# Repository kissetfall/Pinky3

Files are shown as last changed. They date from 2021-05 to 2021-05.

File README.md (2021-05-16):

# Pinky3

Pinky3 fork with rotary encoders and kailh hotswaps for thumb row.
This is a WIP, but it's already works great for daily use.

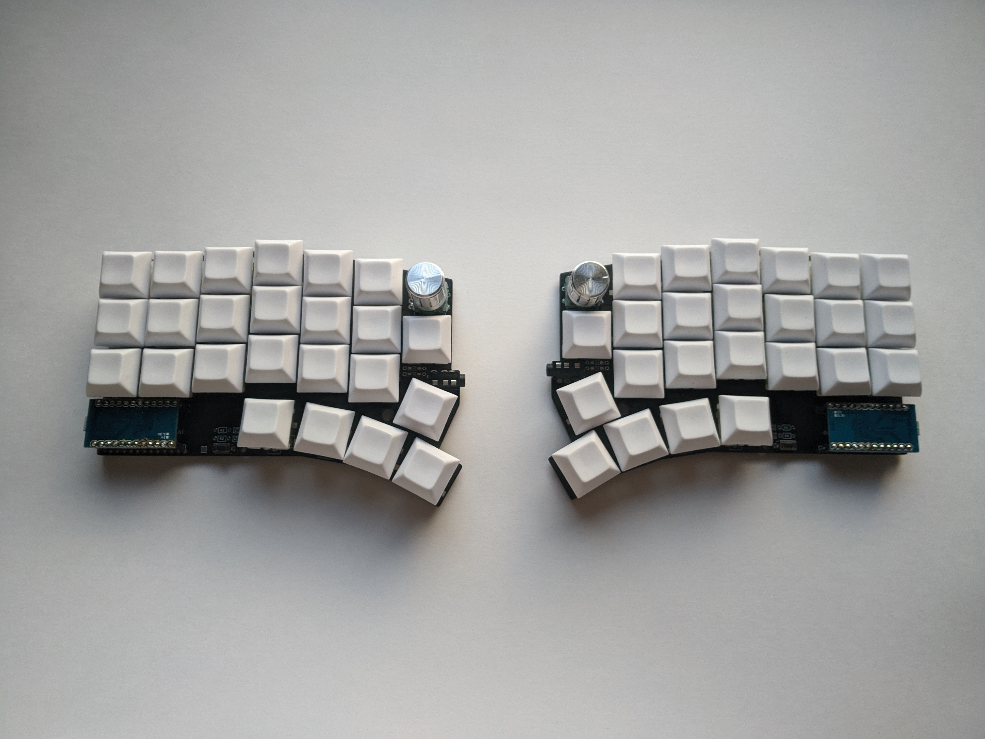
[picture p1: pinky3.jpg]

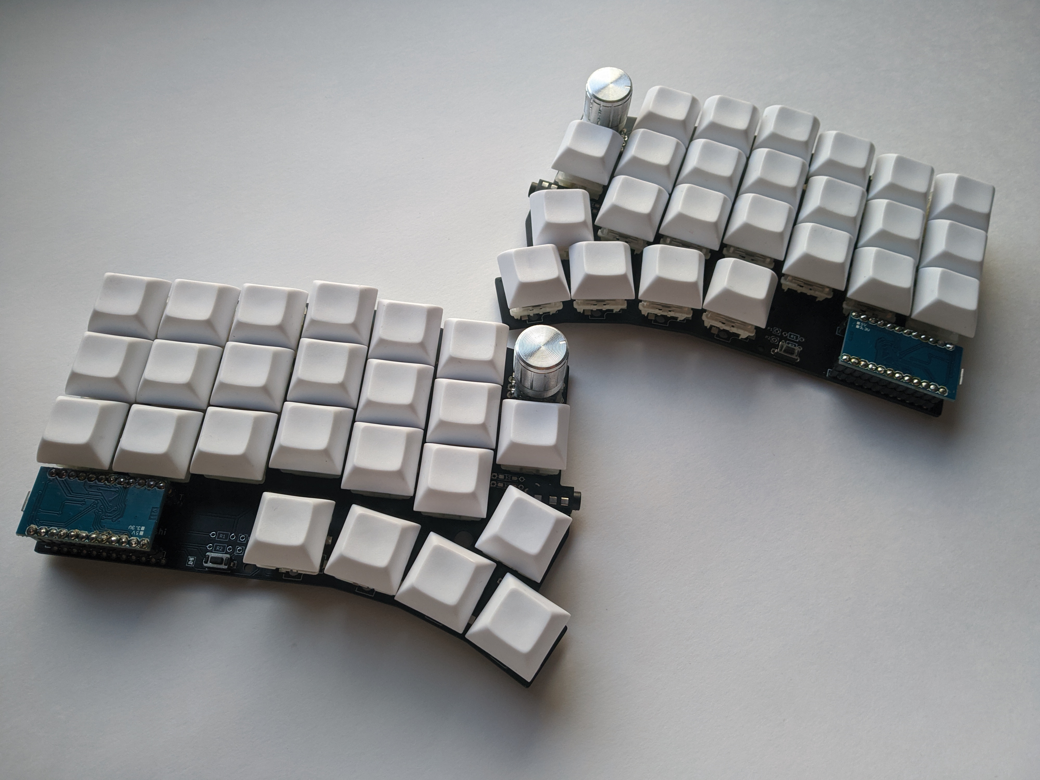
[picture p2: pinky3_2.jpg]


No top/bottom plates are currently available for this board, but it works nice without them.
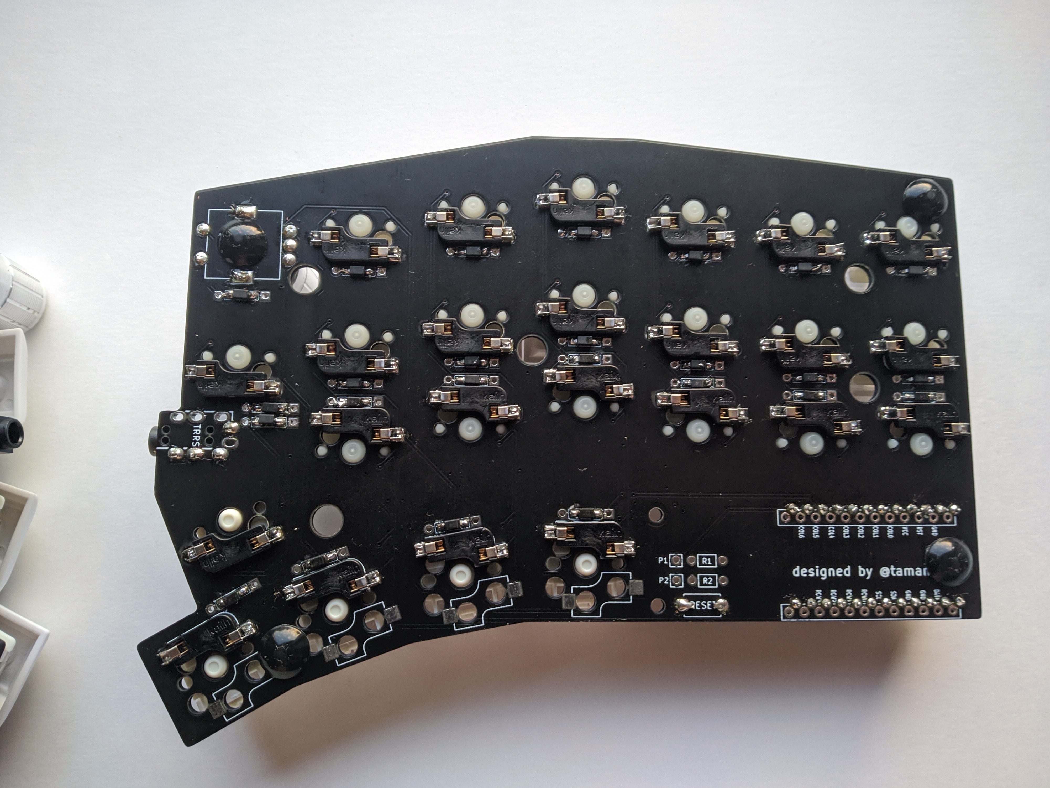
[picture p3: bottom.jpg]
bottom


## Layout
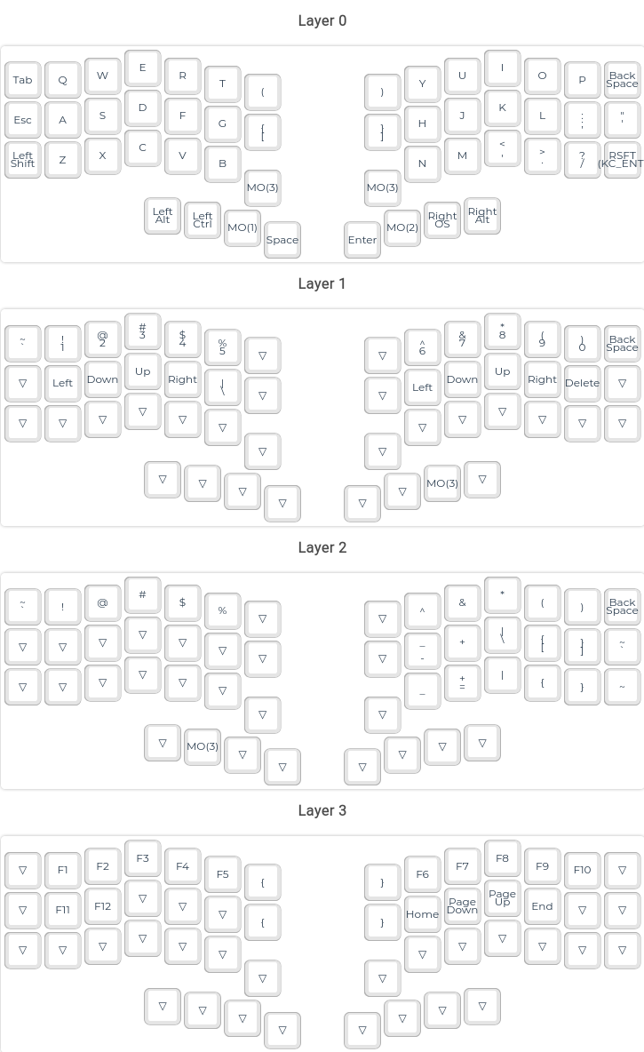
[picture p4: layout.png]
layout


## Firmware

Copy the contents of keymap directory in your qmk/keyboards/pinky/3/keymaps

## TODOs

- [ ] Full choc hotswap support
- [ ] Rework of top, bottom plates, screw holes position.
- [ ] Led strip support
- [ ] Renaming keyboard
- [ ] Build guides, bom, etc.

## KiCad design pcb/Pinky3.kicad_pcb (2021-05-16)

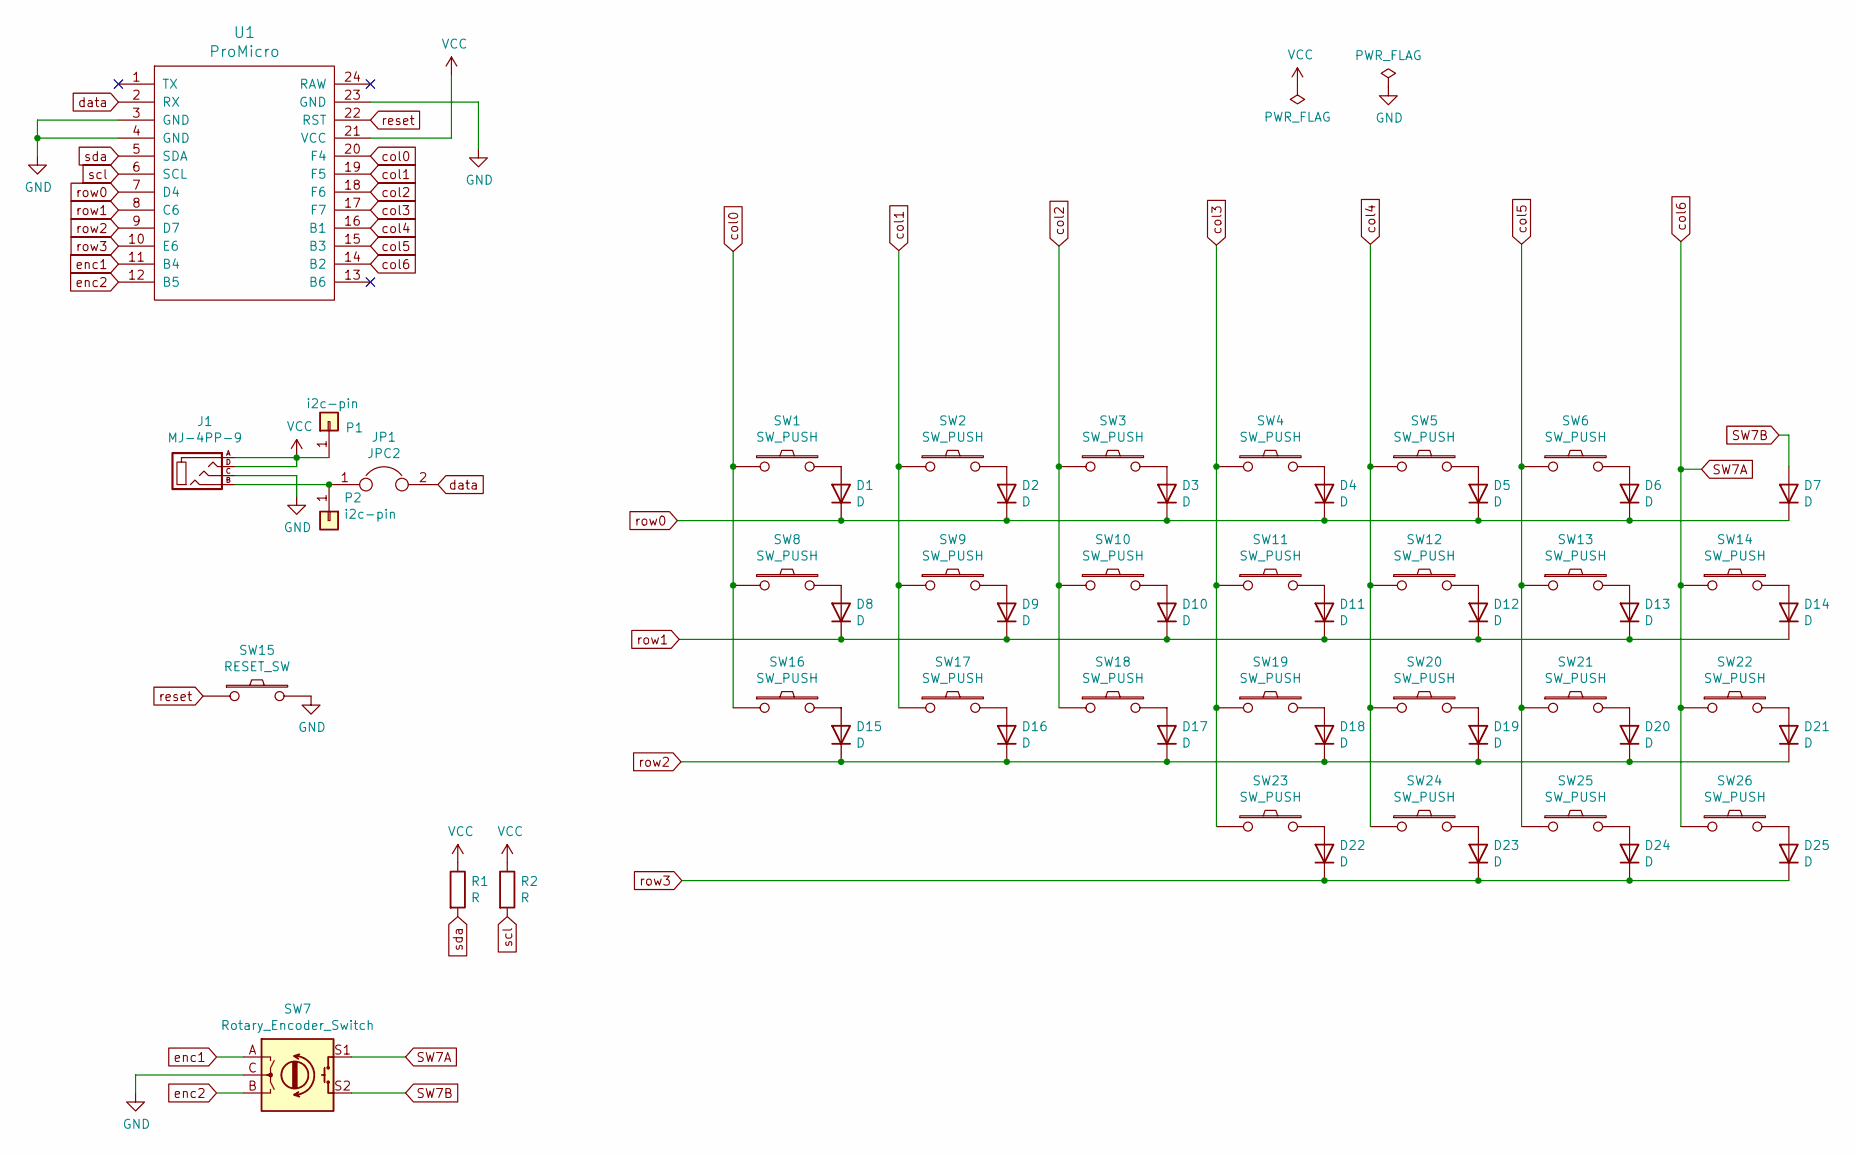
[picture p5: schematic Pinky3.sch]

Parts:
D1, D2, D3, D4, D5, D6, D7, D8, D9, D10, D11, D12, D13, D14, D15, D16, D17, D18, D19, D20, D21, D22, D23, D24, D25: D; D3_TH_SMD
J1: MJ-4PP-9
JP1: JPC2
P1, P2: i2c-pin; 1pin_conn
R1, R2: R
SW1, SW2, SW3, SW4, SW5, SW6, SW8, SW9, SW10, SW11, SW12, SW13, SW14, SW16, SW17, SW18, SW19, SW20, SW21, SW22: SW_PUSH; CherryMX_Hotswap
SW7: Rotary_Encoder_Switch; RotaryEncoder_Alps_EC11E-Switch_Vertical_H20mm-keebio_modif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
SW15: RESET_SW; ResetSW
SW23, SW24, SW25, SW26: SW_PUSH; CherryMX_Choc_Hotswap
U1: ProMicro; ProMicro_v2

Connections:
GND: J1.C, SW7.C, SW15.2, U1.3 (GND), U1.4 (GND), U1.23 (GND)
unnamed: D1.2 (A), SW1.2
unnamed: D2.2 (A), SW2.2
unnamed: D3.2 (A), SW3.2
unnamed: D4.2 (A), SW4.2
unnamed: D5.2 (A), SW5.2
unnamed: D6.2 (A), SW6.2
unnamed: D8.2 (A), SW8.2
unnamed: D9.2 (A), SW9.2
unnamed: D10.2 (A), SW10.2
unnamed: D11.2 (A), SW11.2
unnamed: D12.2 (A), SW12.2
unnamed: D13.2 (A), SW13.2
unnamed: D14.2 (A), SW14.2
unnamed: D15.2 (A), SW16.2
unnamed: D16.2 (A), SW17.2
unnamed: D17.2 (A), SW18.2
unnamed: D18.2 (A), SW19.2
unnamed: D19.2 (A), SW20.2
unnamed: D20.2 (A), SW21.2
unnamed: D21.2 (A), SW22.2
unnamed: D22.2 (A), SW23.2
unnamed: D23.2 (A), SW24.2
unnamed: D24.2 (A), SW25.2
unnamed: D25.2 (A), SW26.2
unnamed: J1.B, JP1.1, P2.1
SW7A: SW7.S1, SW14.1, SW22.1, SW26.1, U1.14 (B2)
SW7B: D7.2 (A), SW7.S2
VCC: J1.A, J1.D, P1.1, R1.1, R2.1, U1.21 (VCC)
col0: SW1.1, SW8.1, SW16.1, U1.20 (F4)
col1: SW2.1, SW9.1, SW17.1, U1.19 (F5)
col2: SW3.1, SW10.1, SW18.1, U1.18 (F6)
col3: SW4.1, SW11.1, SW19.1, SW23.1, U1.17 (F7)
col4: SW5.1, SW12.1, SW20.1, SW24.1, U1.16 (B1)
col5: SW6.1, SW13.1, SW21.1, SW25.1, U1.15 (B3)
data: JP1.2, U1.2 (RX)
enc1: SW7.A, U1.11 (B4)
enc2: SW7.B, U1.12 (B5)
reset: SW15.1, U1.22 (RST)
row0: D1.1 (K), D2.1 (K), D3.1 (K), D4.1 (K), D5.1 (K), D6.1 (K), D7.1 (K), U1.7 (D4)
row1: D8.1 (K), D9.1 (K), D10.1 (K), D11.1 (K), D12.1 (K), D13.1 (K), D14.1 (K), U1.8 (C6)
row2: D15.1 (K), D16.1 (K), D17.1 (K), D18.1 (K), D19.1 (K), D20.1 (K), D21.1 (K), U1.9 (D7)
row3: D22.1 (K), D23.1 (K), D24.1 (K), D25.1 (K), U1.10 (E6)
scl: R2.2, U1.6 (SCL)
sda: R1.2, U1.5 (SDA)

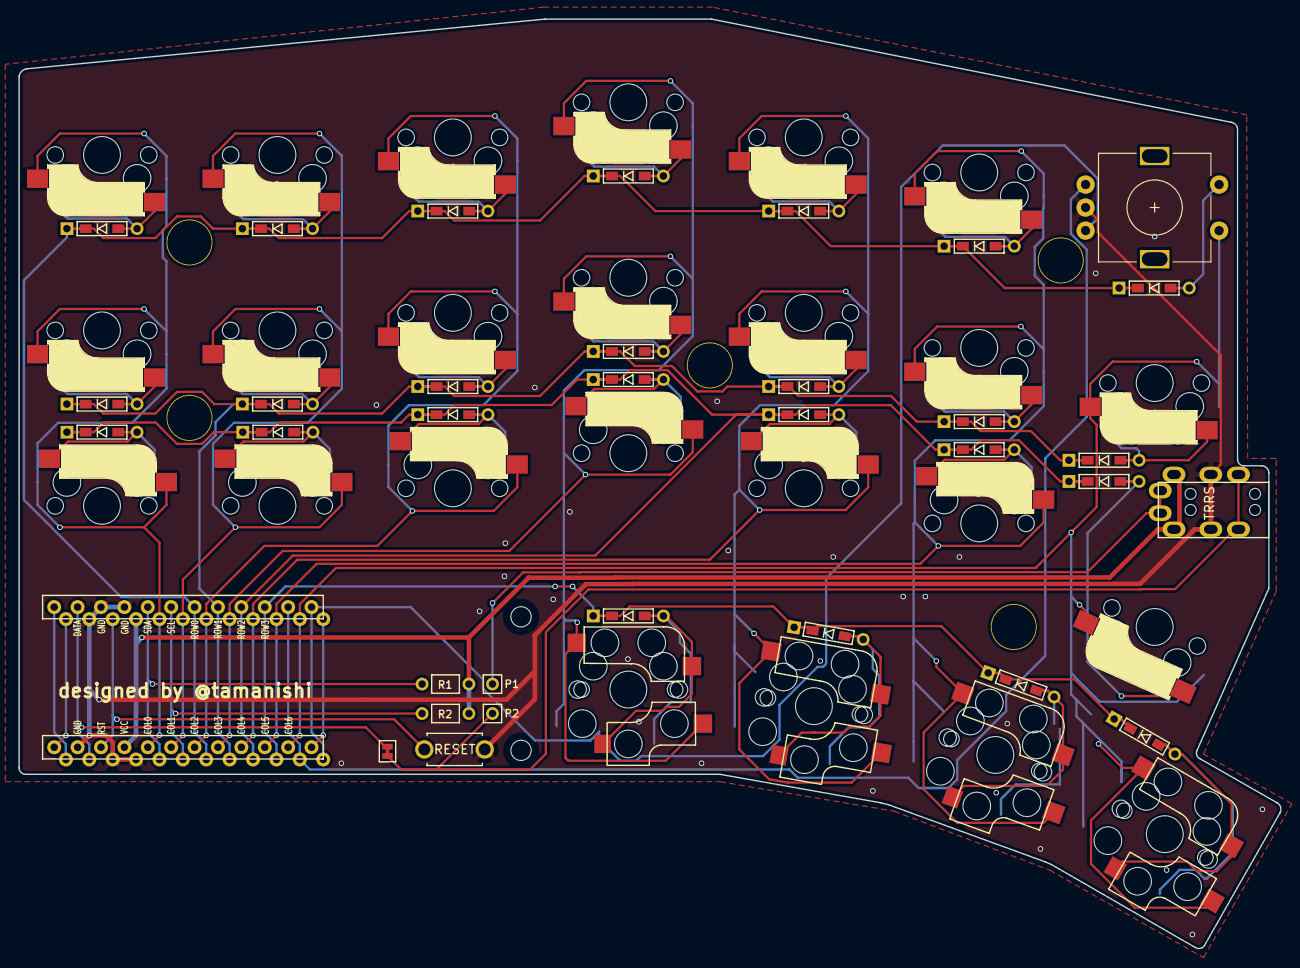
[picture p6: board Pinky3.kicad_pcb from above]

Board: 2 copper layers, 137.0 x 100.9 mm, 65 parts (0 on the bottom side), 45 nets.

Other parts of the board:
HOLE_M2, HOLE_M2#2: VAL**; HOLE_M2
Ref**: Val**; HOLE
Ref**#2, Ref**#3, Ref**#4, Ref**#5: Val**; HOLE

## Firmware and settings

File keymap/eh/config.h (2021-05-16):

/* Copyright 2018 'Masayuki Sunahara'
 *
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
 * You should have received a copy of the GNU General Public License
 * along with this program.  If not, see <http://www.gnu.org/licenses/>.
 */

#pragma once

//#define USE_MATRIX_I2C

/* Select hand configuration */

#define SPLIT_USB_DETECT
//#define MASTER_LEFT
#define EE_HANDS

#define USE_SERIAL_PD2

#define TAPPING_FORCE_HOLD
#define TAPPING_TERM 100

/* Encoder support */
#define ENCODERS_PAD_A { B5 }
#define ENCODERS_PAD_B { B4 }
#define ENCODERS_PAD_A_RIGHT { B4 }
#define ENCODERS_PAD_B_RIGHT { B5 }
#define ENCODER_RESOLUTION 2

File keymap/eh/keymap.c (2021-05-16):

/* Copyright 2018 'Masayuki Sunahara'
 *
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
 * You should have received a copy of the GNU General Public License
 * along with this program.  If not, see <http://www.gnu.org/licenses/>.
 */
#include QMK_KEYBOARD_H

enum layer_names {
    _QWERTY,
    _LOWER,
    _RAISE,
    _ADJUST
};

enum custom_keycodes {
    QWERTY = SAFE_RANGE,
    LOWER,
    RAISE,
    ADJUST
};

#define CTL_TAB CTL_T(KC_TAB)

const uint16_t PROGMEM keymaps[][MATRIX_ROWS][MATRIX_COLS] = {
    [_QWERTY] = LAYOUT_split_3x7_4(
        KC_TAB , KC_Q   , KC_W   , KC_E   , KC_R   , KC_T   , KC_LPRN,    KC_RPRN, KC_Y   , KC_U   , KC_I   , KC_O   , KC_P   , KC_BSPC,
        KC_ESC, KC_A   , KC_S   , KC_D   , KC_F   , KC_G   , KC_LBRC,     KC_RBRC, KC_H   , KC_J   , KC_K   , KC_L   , KC_SCLN, KC_QUOT, 
        KC_LSFT, KC_Z   , KC_X   , KC_C   , KC_V   , KC_B   , ADJUST ,    ADJUST , KC_N   , KC_M   , KC_COMM, KC_DOT , KC_SLSH, SFT_T(KC_ENT),
                                   KC_LALT, KC_LCTL, LOWER  , KC_SPC ,    KC_ENT ,  RAISE , KC_RGUI, KC_RALT
    ),
    [_LOWER] = LAYOUT_split_3x7_4(
        KC_GRV , KC_1   , KC_2   , KC_3   , KC_4   , KC_5   , _______,    _______, KC_6   , KC_7   , KC_8   , KC_9   , KC_0   , KC_BSPC,
        _______, KC_LEFT, KC_DOWN, KC_UP,  KC_RIGHT, KC_CAPS, _______,    _______, KC_LEFT, KC_DOWN,  KC_UP, KC_RIGHT, KC_DEL , _______,
        _______, _______, _______, _______, _______, _______, _______,    _______, _______, _______, _______, _______, _______, _______,
                                   _______, _______, _______, _______,    _______, _______, _______, _______
    ),
    [_RAISE] = LAYOUT_split_3x7_4(
        KC_GRV , KC_EXLM, KC_AT,  KC_HASH, KC_DLR, KC_PERC  , _______,    _______, KC_CIRC, KC_AMPR, KC_ASTR, KC_LPRN, KC_RPRN, KC_BSPC, 
        _______, _______, _______, _______, _______, _______, _______,    _______, KC_MINS, KC_PLUS, KC_BSLS, KC_LBRC, KC_RBRC, KC_GRV,
        _______, _______, _______, _______, _______, _______, _______,    _______, KC_UNDS, KC_EQL, KC_PIPE, KC_LCBR, KC_RCBR, KC_TILD,
                                   _______, _______, _______, _______,    _______, _______, _______, _______
    ),
    [_ADJUST] = LAYOUT_split_3x7_4(
        _______, KC_F1  , KC_F2  , KC_F3  , KC_F4  , KC_F5  , KC_LCBR,    KC_RCBR, KC_F6  , KC_F7  , KC_F8  , KC_F9  , KC_F10 , _______,
        _______, KC_F11 , KC_F12 , _______, _______, _______, KC_LCBR,    KC_RCBR, KC_HOME, KC_PGDN, KC_PGUP, KC_END , _______, _______,
        _______, _______, _______, _______, _______, _______, _______,    _______, _______, _______, _______, _______, _______, _______,
                                   _______, _______, _______, _______,    _______, _______, _______, _______
    )
};
bool process_record_user(uint16_t keycode, keyrecord_t *record) {
    if (record->event.pressed) {
        // set_timelog();
    }

    switch (keycode) {
        case LOWER:
            if (record->event.pressed) {
                layer_on(_LOWER);
                update_tri_layer(_LOWER, _RAISE, _ADJUST);
            } else {
                layer_off(_LOWER);
                update_tri_layer(_LOWER, _RAISE, _ADJUST);
            }
            return false;
            break;
        case RAISE:
            if (record->event.pressed) {
                layer_on(_RAISE);
                update_tri_layer(_LOWER, _RAISE, _ADJUST);
            } else {
                layer_off(_RAISE);
                update_tri_layer(_LOWER, _RAISE, _ADJUST);
            }
            return false;
            break;
        case ADJUST:
            if (record->event.pressed) {
                layer_on(_ADJUST);
            } else {
                layer_off(_ADJUST);
            }
            return false;
            break;
    }
    return true;
}


// Rotary encoder
#ifdef ENCODER_ENABLE
void encoder_update_user(uint8_t index, bool clockwise) {
  if (index == 1) { // Encoder on master side
    if(IS_LAYER_ON(_RAISE)) { // on Raise layer
      // Cursor control
      if (clockwise) {
          tap_code(KC_MNXT);
      } else {
          tap_code(KC_MPRV);
      }
    }
    else {
      if (clockwise) {
          tap_code(KC_VOLU);
      } else {
          tap_code(KC_VOLD);
      }
    }
  }
  else if (index == 0) { // Encoder on slave side
    if(IS_LAYER_ON(_LOWER)) { // on Lower layer
      //
      if (clockwise) {
          tap_code(KC_DOWN);
      } else {
          tap_code(KC_UP);
      }
    }
    else {
      if (clockwise) {
          tap_code(KC_RIGHT);
      } else {
          tap_code(KC_LEFT);
      }
    }
  }
}
#endif

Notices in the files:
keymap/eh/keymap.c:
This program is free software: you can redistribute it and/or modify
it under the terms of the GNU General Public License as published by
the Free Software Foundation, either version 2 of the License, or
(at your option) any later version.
